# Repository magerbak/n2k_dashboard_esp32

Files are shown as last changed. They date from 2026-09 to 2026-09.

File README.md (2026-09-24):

# N2K Dashboard
Monitors the NMEA2000 bus and displays a simple dashboard of relevant sailing info.

* v.1.3.0 and earlier targeted the [Adafruit ESP32-S3 Reverse 1.14" TFT Feather](https://www.adafruit.com/products/5691). This is no longer supported.
* v.2.0.0 and later targets the [Hosyond ESP32-S3 2.8" IPS LCD display](https://a.co/d/04SSH8Cm) with a touch screen.
  * SPI-based 320x240 LCD with the ILI9341 driver.
  * TFT_eSPI GFX library. This project should work pretty seamlessly with any device supported by this library.
  * FT6336 touch device, but the touch logic is very basic and could be adapted to any touch driver.

Relies on the very useful https://github.com/ttlappalainen/NMEA2000 library and a custom version of the [NMEA2000_esp32](https://github.com/offspring/NMEA2000_esp32) library for the ESP32-S3 using the internal CAN controller (external transceiver required).

Approximate power consumption including an external transceiver and 12v to 5v buck converter is about 55mA.

# Overview
Provides top-level pages for wind, logbook and AIS info (at three different ranges). 

All headings and courses are relative to true North and speeds are in knots. Distances are in nautical miles. By default, depth is in feet, pressure in inHg and temperature in Farenheit but the code can be compiled with USE_METRIC defined to switch to meters, millibars and Celcius.

# Wind Info
Displays basic wind and other instrument data.



* The radial dial shows the apparent wind angle (AWA)
* Boat speed (SOG) and course (COG) are in the center in yellow.
* Apparent wind speed (AWS) and angle (AWA) are shown in red at the top with a 1 hour history graph of AWS.
* True wind speed (TWS) and angle (TWA) are shown in blue at the bottom with a 1 hour history graph of TWS.
* Depth is shown to the left in green.

Navigation:
* Tap AWS, TWS, SOG or Depth to view a detailed 60 minute history.
* Tap the Next page icon to the right to cycle to the logbook page.

## History Detail



The history detail page shows a 60 minute history of TWS, AWS, SOG or Depth with a bar showing the range of values occurring during each minute. The maximum, minimum and average values over the last 60 minutes are also shown. The vertical axis is divided every 10 units.

Navigation:
* Tap the graph title to cycle to another history graph.
* Tap anywhere in the body of the graph to return to the wind info page.

# Logbook Info
This page is intended to provide information for making logbook entries or radio calls.



Includes:
* Current time (UTC or Local)
* Ambient atmospheric pressure, air/sea temperature when provided.
* GPS position
* Log (trip) distance and time.
* True heading and course.
* Speed over ground and average trip speed.
* Apparent wind speed and angle
* True wind speed and direction (relative to true North).

The trip log is calculated by sampling GPS position every minute. The log distance and time are saved persistently.

Navigation:
* Tap the time to view historical on-the-hour snapshots.
* Tap the Trip Log to reset (tap again to confirm).
* Tap the Next page icon to the right to cycle to the AIS page.
  
## Logbook History
This page displays a snapshot of most of Logbook info on the hour for the last 4 hours. An initial snapshot is also taken when the system is first powered up once GPS position and time are acquired.



Navigation:
* Tap the time to cycle to a previous snapshot.
* Tap anywhere else to return to the main Logbook info page.

# AIS Info
Displays a North-up graphical representation of AIS targets within the selected range.



* Speed vectors in yellow show projected position in 5 minutes.
* Targets shown in red are considered potential collision issues (closest point of approach is < 1nm within the next hour).
* Selected vessel's range, true bearing and distance are displayed in green at bottom left.
* Selected vessel's MMSI/name is displayed in green at bottom right.
* If the selected vessel is converging, their closest point of approach (CPA) distance, bearing and time (mins) is shown at top right.
  * CPA is red if your vessel is projected to pass in front of the vessel.
  * CPA is orange if your vessel is projected to pass behind the vessel.
* Targets are removed 3 mins after their last report.

Navigation:
* Tap inside the range circles to cycle between targets.
* Tap MMSI/Name in the bottom right to display additional vessel information.
* Tap the range to cycle between 12nm, 6nm, 3nm, 1nm ranges.
* Tap the Next page icon to the right to cycle to the Wind info page.

## AIS Vessel Info
The additional vessel info subpage includes additional static data for the selected vessel such and length, beam and draft, vessel type, status and destination when provided.

PXL_20260921_183305165 MP

Navigation:
* Tap the vessel name to cycle between target.
* Tap anywhere else to return to the main AIS page.

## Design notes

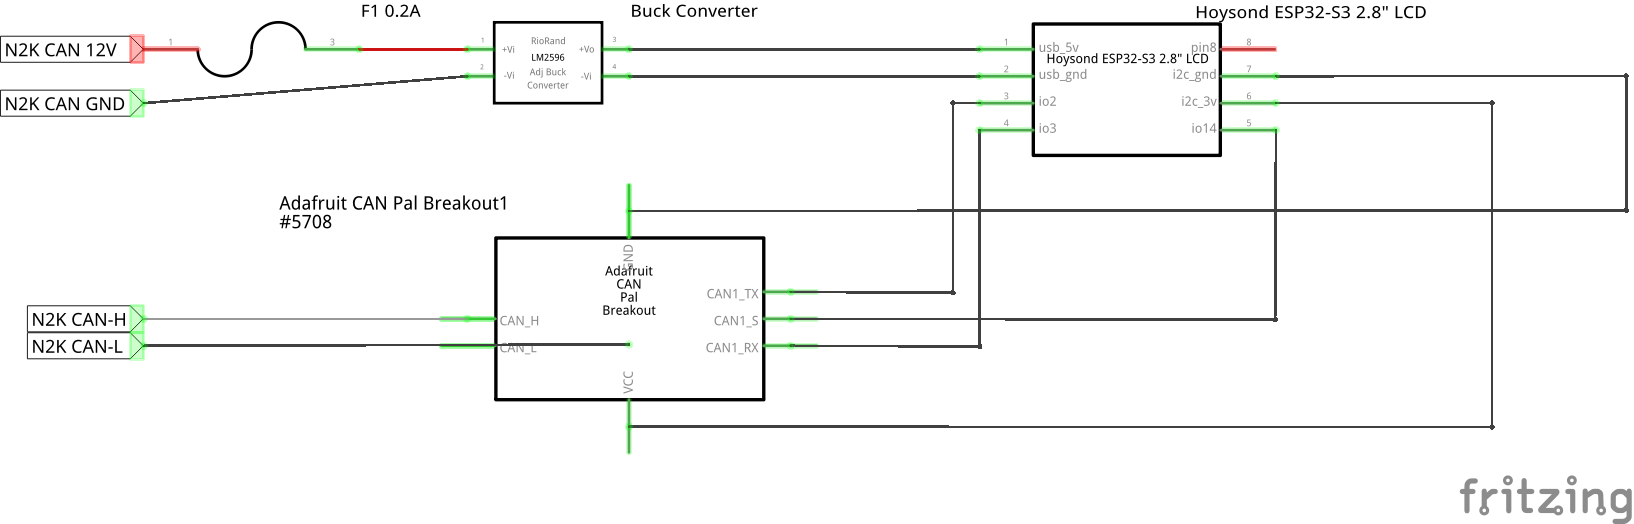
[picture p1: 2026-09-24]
schematics/n2k_dashboard_schem.png

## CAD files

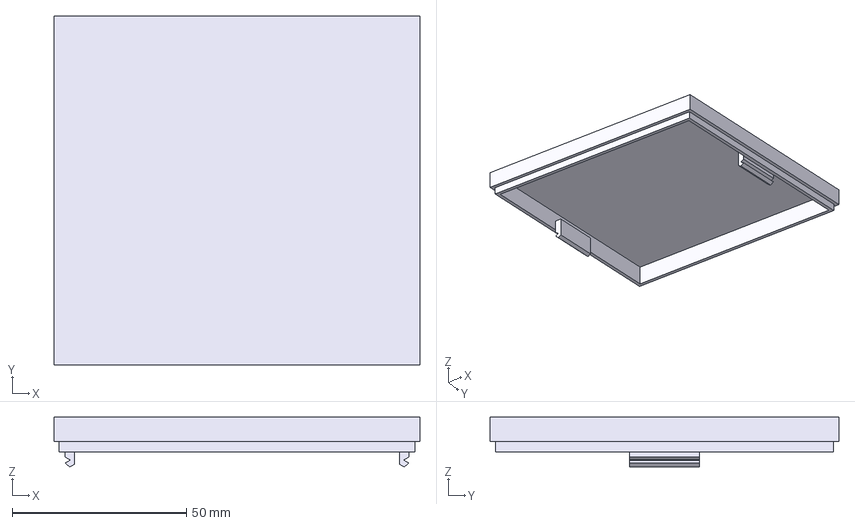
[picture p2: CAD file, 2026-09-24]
assets/NavDeskComboPanelLarge-Lid.step
105.0 x 100.0 x 14.3 mm

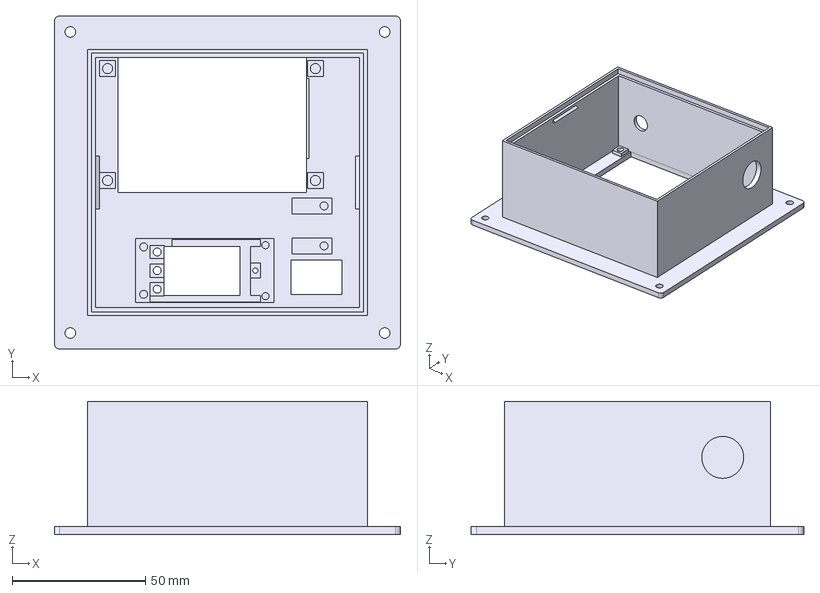
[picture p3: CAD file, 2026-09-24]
assets/NavDeskComboPanelLarge-Panel.step
130.0 x 125.0 x 50.0 mm

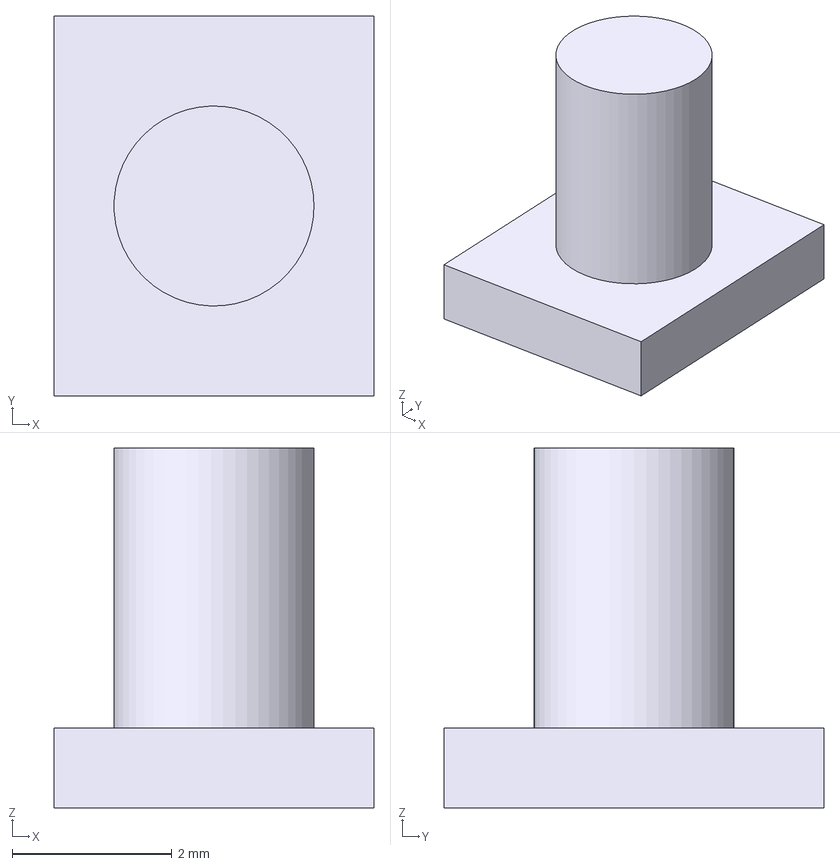
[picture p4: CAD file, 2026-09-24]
assets/NavDeskComboPanelLarge-ButtonActuator.step
4.00 x 4.75 x 4.50 mm

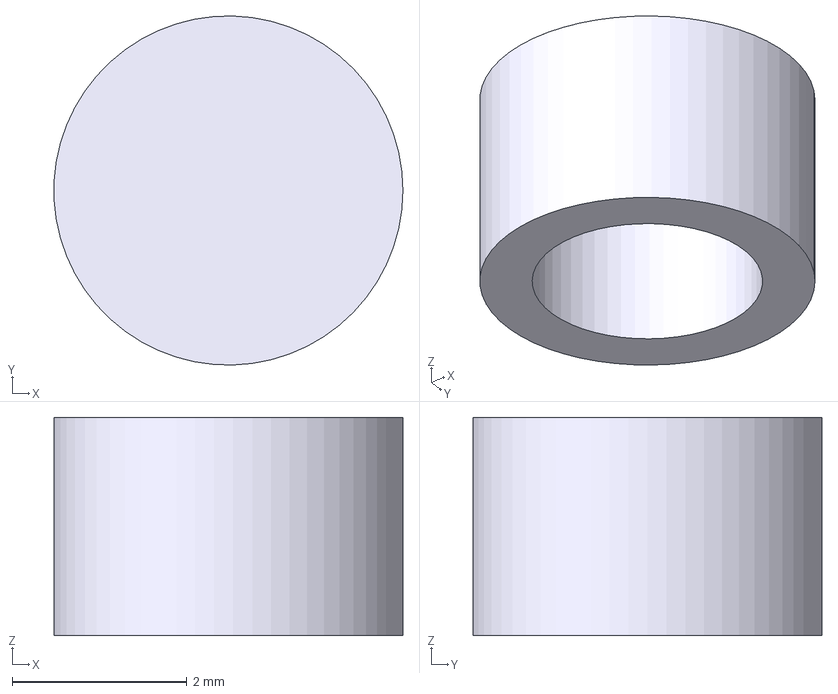
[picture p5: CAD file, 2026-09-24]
assets/NavDeskComboPanelLarge-ButtonActuatorPad.step
4.00 x 4.00 x 2.50 mm

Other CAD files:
assets/NavDeskComboPanelLarge-ButtonActuator.stl
assets/NavDeskComboPanelLarge-ButtonActuatorPad.stl
assets/NavDeskComboPanelLarge-Lid.stl
assets/NavDeskComboPanelLarge-Panel.stl

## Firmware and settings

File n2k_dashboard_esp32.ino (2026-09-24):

/**************************************************************************
  Monitors NMEA2000 bus and displays a simple dashboard of useful info.

  Works with the Hosyond ESP32-S3 2.8" IPS LCD display (https://a.co/d/04SSH8Cm)

  Compiles for Arduino using ESP32-S3 Dev Module board config.

  Uses TFT_eSPI and TFT_eWidget GFX libraries with ILI9341 driver and
  FT6336 touch screen driver.

  Uses the NEMA2000 library for parsing N2K communications using the ESP32
  internal CAN controller (external transceiver required).

 **************************************************************************/
#include "n2k_config.h"      // Build options

#include <limits>
#include <memory>
#include <list>
#include <Preferences.h>     // For persistent storage of log data

#include <TFT_eSPI.h>        // The library itself is modified to select a
                             // User_Setup.h for the appropriate display driver.
#include <TFT_eWidget.h>     // For graphing support
#include <SPI.h>

#define TOUCH_FT6336_SCL 15
#define TOUCH_FT6336_SDA 16
#define TOUCH_FT6336_INT 17
#define TOUCH_FT6336_RST 18
#include <FT6336.h>         // Touch screen uses I2C

#include "N2kMsg.h"
#include "NMEA2000.h"
#define ESP32_CAN_SILENT_PIN GPIO_NUM_14
#define ESP32_CAN_TX_PIN GPIO_NUM_2
#define ESP32_CAN_RX_PIN GPIO_NUM_3
#include <NMEA2000_esp32.h> // Custom NMEA2000_esp32 support for S3 (https://github.com/offspring/NMEA2000_esp32)
#include <N2kMessages.h>

#include "simple_timer.h"
#include "data_history.h"
#include "n2kvector.h"
#include "n2kpos.h"
#include "n2kunits.h"
#include "n2kaistarget.h"
#include "touch_rect.h"

#define VERSION_NUM      "v2.0.0"
#define UPDATE_INTERVAL  1
#define AIS_TIMEOUT      (3 * 60 + 10)

// Default magnetic variation, in case this is not provided from the network.
// Modify this value based on the region of operation.
#define DEFAULT_MAGNETIC_VARIATION (-14.0 * (M_PI / 180.0))  // Variation for Boston, MA in 2025.

// Interval that min/max data is sampled.
#define HISTORY_SAMPLE_INTERVAL_MS          1000
// Interval over which sampled min/max data is aggregated per data point in history.
#ifdef TESTING
  #define HISTORY_AGGREGATION_INTERVAL_MS   (10 * 1000)
  #define LOG_SAVE_INTERVAL_MS              (2 * 60 * 1000)
#else
  #define HISTORY_AGGREGATION_INTERVAL_MS   (60 * 1000)
  #define LOG_SAVE_INTERVAL_MS              (10 * 60 * 1000)
#endif
// Default number of data points in history - can be customized in setup().
// Total duration of history = num data points * HISTORY_AGGREGATION_INTERVAL_MS
#define HISTORY_DEF_NUM_DATA_POINTS         60

#define DISPLAY_WIDTH   320
#define DISPLAY_HEIGHT  240

#define ARROW_HEIGHT    25
#define ARROW_WIDTH     12

#define NUM_LOG_ENTRIES 4

// Display page
enum Page {
    PAGE_WIND,
    PAGE_POSITION,
    PAGE_AIS,

    NUM_PAGES
};

enum Subpage {
    SUBPAGE_NONE,

    // Wind supbages
    SUBPAGE_HIST_AWS,
    SUBPAGE_HIST_TWS,
    SUBPAGE_HIST_SOG,
    SUBPAGE_HIST_DEPTH,
    SUBPAGE_HIST_SEPARATOR,

    // Position subpages
    SUBPAGE_POS_LOG,

    // AIS subpages
    SUBPAGE_AIS_INFO,
};

enum Event {
    EVT_NONE,
    EVT_D0_PRESS,
    EVT_D0_RELEASE,
    EVT_D1_PRESS,
    EVT_D1_RELEASE,
    EVT_D2_PRESS,
    EVT_D2_RELEASE,
};

enum TextLayout {
    TXT_JUSTIFIED,
    TXT_CENTERED,
};

struct HistStatsContext {
    bool bFirst = true;

    size_t len = 0;     // Num samples of history

    // Stats for current history samples.
    double min = 0.0;
    double max = 1.0;
    double avg = 0.0;
};

// Trip log
struct LogData {
    uint32_t duration;
    float distance;
};

struct LogEntry {
    bool bInUse;

    uint16_t timestamp;     // minutes since midnight
    int16_t tzOffset;       // timezone offset or 0 if unknown.

    N2kPos position;
    double heading;
    N2kVector velocity;
    N2kVector appWind;
    LogData logData;
    float atmPressure;
    float atmTemp;
    float seaTemp;
};

// Abbreviations for TFT_eSPI fonts.
#define GFXFF 1

// These are modified versions of the standard GFX FreeFonts with the same
// filename, that replace the '~' character with the '°' symbol for convenience.
// The Fonts directory includes the 48 fonts from the TFT_eSPI library but we
// only include 3.
#include "Fonts/FreeSansBold9pt7b.h"
#include "Fonts/FreeSansBold12pt7b.h"
#include "Fonts/FreeSansBold18pt7b.h"

// The font names have a Mod suffix to distinguish them from the stock fonts.
#define FONT_SMALL  &FreeSansBoldMod9pt7b
#define FONT_MEDIUM &FreeSansBoldMod12pt7b
#define FONT_LARGE  &FreeSansBoldMod18pt7b

// fontHeight() returns a line-spacing that accounts for ascending and descending
// lowercase characters. Since we are primarily using uppercase, this additional
// spacing looks overly generous, so we use a more compact spacing instead.
#define FONT_SMALL_ADJ_HEIGHT   (21 - 5)
#define FONT_MEDIUM_ADJ_HEIGHT  (28 - 6)
#define FONT_LARGE_ADJ_HEIGHT   (42 - 9)

// Pin usage as follow:
//             CS  DC/RS  RESET  SDI/MOSI  SCK  SDO/MISO  LED    VCC     GND
// ESP32-S3:   10    2      15      11      12      13     21     5V     GND
TFT_eSPI g_tft;

// Default orientation is portrait (240x320)
FT6336 g_ts = FT6336(TOUCH_FT6336_SDA, TOUCH_FT6336_SCL, TOUCH_FT6336_INT,
                     TOUCH_FT6336_RST, DISPLAY_HEIGHT, DISPLAY_WIDTH);

tNMEA2000 &g_NMEA2000 = *(new tNMEA2000_esp32());

// UI state
Page g_page = PAGE_WIND;
Subpage g_subpage = SUBPAGE_NONE;
double g_aisRange = 12.0;

// Common to all pages
TouchRect g_nextPageRect;

// Wind Page touch rects
TouchRect g_awsRect;
TouchRect g_depthRect;
TouchRect g_twsRect;
TouchRect g_sogRect;

// Position Page touch rects
TouchRect g_timeRect;
TouchRect g_logResetRect;

// AIS Page touch rects
TouchRect g_rangeRect;
TouchRect g_selectRect;
TouchRect g_detailRect;

// Subpage rects
TouchRect g_subTitleRect;
TouchRect g_subBodyRect;

float g_envAtmPressure = std::numeric_limits<float>::quiet_NaN();
float g_envAtmTemp = std::numeric_limits<float>::quiet_NaN();
float g_envAtmHumidity = std::numeric_limits<float>::quiet_NaN();
float g_envSeaTemp = std::numeric_limits<float>::quiet_NaN();;

#ifdef USE_METRIC_PRESSURE
static const int g_precPressure = 0;
static const char g_unitsPressure[] = "mb";
#else
static const int g_precPressure = 2;
static const char g_unitsPressure[] = { '"', '\0' };
#endif
#ifdef USE_METRIC
static const char g_unitsTemp[] = "C";
static const char g_unitsDepth[] = "m";
#else
static const char g_unitsTemp[] = "F";
static const char g_unitsDepth[] = "ft";
#endif

// Log data
Preferences g_prefs;
LogData g_tripLog;          // Duration and distance of current trip
bool g_tripResetConfirmation = false;
N2kPos g_lastPos;           // Lat/Long of last log sample

LogEntry g_logEntries[NUM_LOG_ENTRIES];
unsigned int g_logEntryIndex;   // Index of next entry to store.
unsigned int g_selLogEntry; // Reverse index of displayed entry

uint16_t g_date;            // Days since 1/1/1970
double g_secsSinceMidnight; // Seconds since midnight
int16_t g_tzOffset;         // Timezone offset in minutes, if known

bool g_bPosValid = false;
N2kPos g_localPos;          // Latitude and Longitude
N2kVector g_localVelocity;  // Boat COG (in degrees) and SOG (kts) as a vector
double g_hdg = 0.0;         // degrees
double g_variation = DEFAULT_MAGNETIC_VARIATION; // radians

double g_depth = 0.0;       // ft
N2kVector g_appWind;        // Degrees, knots
N2kVector g_trueWind;       // Degrees, knots

// AIS state
std::list<std::unique_ptr<N2kAISTarget>> g_targets;
uint32_t g_selTarget = 0;   // MMSI of selected AIS target

// 1s timer for refreshing data model (ageing out AIS targets, sampling data history).
SimpleTimer g_updateTimer;

// 60s timer for recording aggregate min/max history and log data.
SimpleTimer g_historyTimer;

// 10min timer to save trip log data
SimpleTimer g_tripLogTimer;

// Timer for recording on-the-hour log entries
SimpleTimer g_hourTimer;

MinMaxDataHistory<double> g_awsHistory;
MinMaxDataHistory<double> g_twsHistory;
MinMaxDataHistory<double> g_sogHistory;
MinMaxDataHistory<double> g_depthHistory;

// Time since last display update in seconds.
time_t g_lastUpdate = 0;

void setup(void) {
  Serial.begin(115200);
  delay(2000);
  Serial.println(F("Starting N2K dashboard"));

  g_prefs.begin("n2k_dashboard");

  g_tripLog.duration = g_prefs.getUInt("tripLogTime", 0);
  g_tripLog.distance = g_prefs.getFloat("tripLogDist", 0.0);

  // Optionally, set N2k transceiver to silent mode. This only works if there is
  // more than one device on the N2K network. If testing with a single transmitter,
  // then our transmit must remain enabled so it can ACK messages.
  pinMode(ESP32_CAN_SILENT_PIN, OUTPUT);
  digitalWrite(ESP32_CAN_SILENT_PIN, LOW /* HIGH */); // not silent

  g_updateTimer.begin(nullptr, HISTORY_SAMPLE_INTERVAL_MS, updateCallback);
  g_historyTimer.begin(nullptr, HISTORY_AGGREGATION_INTERVAL_MS, historyCallback);
  g_tripLogTimer.begin(nullptr, LOG_SAVE_INTERVAL_MS, logCallback);

  // Record history of AWS, TWS and SOG for last 60mins.
  g_awsHistory.begin(60);
  g_twsHistory.begin(60);
  g_sogHistory.begin(60);
  g_depthHistory.begin(60);

  // initialize TFT
  g_tft.init();
  g_tft.setRotation(1);
  g_ts.begin();
  g_ts.setRotation(1);

  setupTouchRects();

  displaySplashScreen();

  delay(1000);
  displayUpdate(true);

  //NMEA2000.SetN2kCANMsgBufSize(8);
  //NMEA2000.SetN2kCANReceiveFrameBufSize(100);
  g_NMEA2000.EnableForward(false);  // Disable all msg forwarding to USB (=Serial)
  g_NMEA2000.SetMsgHandler(handleNMEA2000Msg);
  g_NMEA2000.Open();
  Serial.println(F("N2k Initialized"));
}

void loop() {
    uint32_t t = millis();

    handleTouchEvents();

    // Drive our timers
    g_updateTimer.tick(t);
    g_historyTimer.tick(t);
    g_tripLogTimer.tick(t);
    g_hourTimer.tick(t);

    // Handle incoming N2K messages.
    g_NMEA2000.ParseMessages();
}

void setupTouchRects() {
    g_nextPageRect.init(DISPLAY_WIDTH - ARROW_WIDTH - 30, DISPLAY_HEIGHT / 2 - ARROW_HEIGHT / 2 - 10,
                        ARROW_WIDTH + 15 + 15, ARROW_HEIGHT + 10 * 2);
    g_nextPageRect.setReleaseCallback(handleNextPageCallback, nullptr);

    g_awsRect.init(0, 0, 70, 60);
    g_awsRect.setReleaseCallback(handleAwsCallback,  nullptr);

    g_depthRect.init(0, DISPLAY_HEIGHT / 2 - 30, 70, 60);
    g_depthRect.setReleaseCallback(handleDepthCallback,  nullptr);

    g_twsRect.init(0, DISPLAY_HEIGHT - 60, 70, 60);
    g_twsRect.setReleaseCallback(handleTwsCallback,  nullptr);

    g_sogRect.init(DISPLAY_WIDTH / 2 - 40, DISPLAY_HEIGHT / 2 - 40, 80, 80);
    g_sogRect.setReleaseCallback(handleSogCallback,  nullptr);


    g_timeRect.init(0, 0, DISPLAY_WIDTH / 2, 40);
    g_timeRect.setReleaseCallback(handleTimeCallback,  nullptr);

    g_logResetRect.init(0, FONT_MEDIUM_ADJ_HEIGHT * 4 - 5, DISPLAY_WIDTH / 2, FONT_MEDIUM_ADJ_HEIGHT + 15);
    g_logResetRect.setReleaseCallback(handleLogResetCallback,  nullptr);


    g_rangeRect.init(0, 0, DISPLAY_WIDTH / 3, 50);
    g_rangeRect.setReleaseCallback(handleRangeCallback,  nullptr);

    g_selectRect.init(DISPLAY_WIDTH / 2 - 90, DISPLAY_HEIGHT / 2 - 60, 180, 120);
    g_selectRect.setReleaseCallback(handleSelectCallback,  nullptr);

    g_detailRect.init(DISPLAY_WIDTH - DISPLAY_WIDTH / 2, DISPLAY_HEIGHT - 40, DISPLAY_WIDTH / 2, 40);
    g_detailRect.setReleaseCallback(handleDetailCallback,  nullptr);

    g_subTitleRect.init(0, 0, DISPLAY_WIDTH, 50);
    g_subTitleRect.setReleaseCallback(handleSubTitleCallback,  nullptr);

    g_subBodyRect.init(0, 40, DISPLAY_WIDTH, DISPLAY_HEIGHT - 50);
    g_subBodyRect.setReleaseCallback(handleSubBodyCallback,  nullptr);
}


void handleTouchEvents() {
    uint16_t x = 0;
    uint16_t y = 0;
    bool bPressed = false;

    g_ts.read();
    if (g_ts.isTouched) {
        x = g_ts.points[0].x;
        y = g_ts.points[0].y;
        bPressed = true;
    }

    if (g_subpage == SUBPAGE_NONE) {
        // All top level pages have a next page button
        g_nextPageRect.update(bPressed, x, y);

        switch (g_page) {
            case PAGE_WIND:
                g_awsRect.update(bPressed, x, y);
                g_depthRect.update(bPressed, x, y);
                g_twsRect.update(bPressed, x, y);
                g_sogRect.update(bPressed, x, y);
                break;

            case PAGE_POSITION:
                g_timeRect.update(bPressed, x, y);
                g_logResetRect.update(bPressed, x, y);
                break;

            case PAGE_AIS:
                g_rangeRect.update(bPressed, x, y);
                g_selectRect.update(bPressed, x, y);
                g_detailRect.update(bPressed, x, y);
                break;
        }
    }
    else {
        // For now subpages only care about touch events to the first row of
        // text or the rest of the page.
        g_subTitleRect.update(bPressed, x, y);
        g_subBodyRect.update(bPressed, x, y);
    }
}

void handleNextPageCallback(void* user) {
    int pg = (int)g_page + 1;
    if (pg >= NUM_PAGES) {
        pg = PAGE_WIND;
    }
    g_page = (Page)pg;
    g_tripResetConfirmation = false;

    displayUpdate(true);
}

void handleAwsCallback(void* user) {
    g_subpage = SUBPAGE_HIST_AWS;

    displayUpdate(true);
}

void handleDepthCallback(void* user) {
    g_subpage = SUBPAGE_HIST_DEPTH;

    displayUpdate(true);
}

void handleTwsCallback(void* user) {
    g_subpage = SUBPAGE_HIST_TWS;

    displayUpdate(true);
}

void handleSogCallback(void* user) {
    g_subpage = SUBPAGE_HIST_SOG;

    displayUpdate(true);
}

void handleTimeCallback(void* user) {
    g_selLogEntry = 0;
    g_subpage = SUBPAGE_POS_LOG;
    g_tripResetConfirmation = false;

    displayUpdate(true);
}

void handleLogResetCallback(void* user) {
   if (g_tripResetConfirmation) {
        g_tripLog.duration = 0;
        g_tripLog.distance = 0.0;
        g_prefs.putUInt("tripLogTime", g_tripLog.duration);
        g_prefs.putFloat("tripLogDist", g_tripLog.distance);
        g_tripResetConfirmation = false;
    }
    else {
        g_tripResetConfirmation = true;
    }
}

void handleRangeCallback(void* user) {
    // Cycle through ranges
    if (g_aisRange == 1.0) {
        g_aisRange = 12.0;
    }
    else if (g_aisRange == 3.0) {
        g_aisRange = 1.0;
    }
    else {
        g_aisRange = g_aisRange / 2.0;
    }

    displayUpdate(true);
}

void handleSelectCallback(void* user) {
    // Cycle forward through targets
    setTarget(cycleAisTarget(g_targets, g_selTarget));

    displayUpdate(true);
}

void handleDetailCallback(void* user) {
    g_subpage = SUBPAGE_AIS_INFO;

    displayUpdate(true);
}

void handleSubTitleCallback(void* user) {
    switch (g_subpage) {
        case SUBPAGE_HIST_AWS:
        case SUBPAGE_HIST_TWS:
        case SUBPAGE_HIST_SOG:
        case SUBPAGE_HIST_DEPTH:
            {
                int sub = (int)g_subpage + 1;
                if (sub >= SUBPAGE_HIST_SEPARATOR) {
                    sub = SUBPAGE_HIST_AWS;
                }
                g_subpage = (Subpage)sub;
            }
            break;

        case SUBPAGE_POS_LOG:
            {
                unsigned int ix = (g_selLogEntry + 1) % NUM_LOG_ENTRIES;
                if (g_logEntries[ix].bInUse == false) {
                    ix = 0;
                }
                g_selLogEntry = ix;
            }
            break;

        case SUBPAGE_AIS_INFO:
            // Cycle forward through targets
            setTarget(cycleAisTarget(g_targets, g_selTarget));
            break;
    }

    displayUpdate(true);
}

void handleSubBodyCallback(void* user) {
    g_subpage = SUBPAGE_NONE;

    displayUpdate(true);
}


void drawArrowRight(int16_t x, int16_t y) {
    g_tft.drawWideLine(x - ARROW_WIDTH, y - ARROW_HEIGHT / 2, x, y, 5, TFT_DARKGREY);
    g_tft.drawWideLine(x, y, x - ARROW_WIDTH, y + ARROW_HEIGHT / 2, 5, TFT_DARKGREY);
}


const N2kAISTarget* cycleAisTarget(const std::list<std::unique_ptr<N2kAISTarget>>& targets,
                                   uint32_t selMmsi) {
    const N2kAISTarget* last = nullptr;

    for (auto& t : targets) {
        if (!isVisibleTarget(t.get())) {
            continue;
        }

        if (selMmsi == 0 || (last && last->getMmsi() == selMmsi)) {
            return t.get();
        }
        last = t.get();
    }

    return nullptr;
}

// Time-based refresh of our data model. This may update the display based on
// what changes.
bool updateCallback(void* user) {
    bool bChanged = false;
    time_t now = time(nullptr);

    (void)user;

    // Age out stale AIS targets
    for (auto t = g_targets.begin(); t != g_targets.end();) {
        if ((*t)->getTimestamp() && now - (*t)->getTimestamp() > AIS_TIMEOUT) {
            if ((*t)->getMmsi() == g_selTarget) {
                setTarget(nullptr);
            }
            t = g_targets.erase(t);
            bChanged = true;
        }
        else {
            ++t;
        }
    }

    // Update the min/max value for current history data point.
    g_awsHistory.updateData(g_appWind.getMagnitude());
    g_twsHistory.updateData(g_trueWind.getMagnitude());
    g_sogHistory.updateData(g_localVelocity.getMagnitude());
    g_depthHistory.updateData(g_depth);

    if (bChanged) {
        displayUpdate(true);
    }

    // Continue running
    return true;
}

bool historyCallback(void* user) {
    // Record the next data point for each history.
    g_awsHistory.updateHistory();
    g_twsHistory.updateHistory();
    g_sogHistory.updateHistory();
    g_depthHistory.updateHistory();

    // Sample position and accumulate running distance and time
    if (g_bPosValid) {
        N2kVector dist = g_localPos.getRelDistance(g_lastPos);
        g_tripLog.duration += HISTORY_AGGREGATION_INTERVAL_MS / 1000;
        g_tripLog.distance += dist.getMagnitude();
        g_lastPos = g_localPos;
    }

    // Force a display refresh every so often even if we're not receiving data
    displayUpdate(true);

    // Continue running
    return true;
}

bool logCallback(void* user) {
    // Persist the accumulated log data
    g_prefs.putUInt("tripLogTime", g_tripLog.duration);
    g_prefs.putFloat("tripLogDist", g_tripLog.distance);

    // Continue running
    return true;
}

bool logEntryCallback(void* user) {
    // Snapshot logbook entry data on the hour
    addLogEntry();

    // Make sure next interval is 1hr because the first time it is not.
    SimpleTimer* t = (SimpleTimer*)user;
    if (t) {
        t->setInterval(3600 * 1000);
    }
    return true;
}

void displaySplashScreen() {
    g_tft.fillScreen(TFT_BLACK);

    // Version in bottom right
    g_tft.setFreeFont(FONT_SMALL);
    g_tft.setTextSize(1);
    g_tft.setTextColor(TFT_YELLOW);

    g_tft.setTextDatum(BR_DATUM);
    g_tft.drawString(VERSION_NUM, DISPLAY_WIDTH, DISPLAY_HEIGHT, GFXFF);

    // Welcome message centered
    g_tft.setFreeFont(FONT_MEDIUM);
    g_tft.setTextColor(TFT_GREEN, TFT_BLACK);

    g_tft.setTextDatum(MC_DATUM);
    g_tft.drawString("Hello Michael", DISPLAY_WIDTH / 2, DISPLAY_HEIGHT / 2, GFXFF);

    g_tft.setTextDatum(TL_DATUM);
}

// Helper function to print a floating point value using a calculated starting
// position based on its displayed length and a layout option.
void drawJustifiedVal(double val, int precision, const char* suffix, int x, int y, int datum) {
    char str[64];

    if (!suffix) {
        suffix = "";
    }

    int rc = snprintf(str, sizeof(str), "%.*f%s", precision, val, suffix);

    g_tft.setTextDatum(datum);
    g_tft.drawString(str, x, y);
}


//
// Wind info top-level page.
//
void displayPageWind() {
    const int radius = 90;
    GraphWidget graph1(&g_tft);
    GraphWidget graph2(&g_tft);

    int x0 = DISPLAY_WIDTH / 2;
    int y0 = DISPLAY_HEIGHT / 2;

    g_tft.setTextWrap(false);

    // Wind info in large font
    g_tft.setFreeFont(FONT_LARGE);

    g_tft.fillScreen(TFT_BLACK);
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

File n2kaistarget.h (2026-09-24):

#pragma once

#include <stdint.h>
#include <stddef.h>
#include <time.h>

#include "n2kpos.h"
#include "n2kvector.h"
#include "n2kcpa.h"

// Represents an AIS target.
//
// MMSI is used as the unique identifier for each object and is required at
// construction time.
//
// Depending on which messages have been subsequently received, only a subset
// of information may be populated.
//
// In particular, static vessel info (length, name, etc) is generally received
// separately from dynamic info (position, speed, etc). Class B reports contain
// a subset of class A information.
//
// getTimestamp will return 0 until dynamic data has been set.
//
// getName will return the MMSI in the absence of static vessel name info.
//
// calcCPA will be ignored until dynamic position info has been received.
class N2kAISTarget
{
public:
    N2kAISTarget(uint32_t mmsi);
    ~N2kAISTarget() = default;

    enum AISClass {
        CLASS_B,
        CLASS_A,
    };

    enum NavStatus {
        NAV_STATUS_UNDER_WAY_MOTORING = 0,
        NAV_STATUS_AT_ANCHOR = 1,
        NAV_STATUS_NOT_UNDER_COMMAND = 2,
        NAV_STATUS_RESTRICTED_MANOEUVERABILITY = 3,
        NAV_STATUS_CONSTRAINED_BY_DRAUGHT = 4,
        NAV_STATUS_MOORED = 5,
        NAV_STATUS_AGROUND = 6,
        NAV_STATUS_FISHING = 7,
        NAV_STATUS_UNDER_WAY_SAILING = 8,
        NAV_STATUS_HAZARDOUS_MATERIAL_HIGH_SPEED = 9,
        NAV_STATUS_HAZARDOUS_MATERIAL_WING_IN_GROUND = 10,
        NAV_STATUS_AIS_SART = 14,
    };

    const time_t getTimestamp() const { return m_timestamp; }
    uint32_t getMmsi() const { return m_mmsi; }
    const char* getName() const { return m_name; }
    AISClass getClass() const { return m_class; }

    const char* getDest() const { return m_dest; }

    NavStatus getNavStatus() const { return m_navStatus; }
    const char* getNavStatusStr() const;

    uint8_t getVesselType() const { return m_type; }
    const char* getVesselTypeStr() const;

    double getLength() const { return m_length; }
    double getBeam() const { return m_beam; }
    double getDraft() const { return m_draft; }

    void update(const N2kPos &pos, const N2kVector &vel, NavStatus status);
    void update(const N2kPos& pos, const N2kVector& vel);
    void update(const char* name);
    void update(uint8_t type, double length, double beam, double draft,
                const char* callsign, const char* name, const char* dest);

    void calcCpa(const N2kPos &ref, const N2kVector &refVelocity);
    const N2kVector& getRelDistance() const { return m_relDistance; }
    const N2kVector& getVelocity() const { return m_velocity; }
    const Cpa* getCpa() const { return &m_cpa; }

    bool toString(char* buffer, size_t len) const;
    bool toStringVesselInfo(char* buffer, size_t len) const;

private:
    static const char* s_navStatusTable[NAV_STATUS_AIS_SART + 1];
    static bool copyTrimmed(char* dest, const char* src, size_t size);

    // Time of last position update
    time_t m_timestamp = 0;

    uint32_t m_mmsi = 0;
    AISClass m_class = CLASS_B;

    N2kPos m_pos;
    N2kVector m_velocity;
    NavStatus m_navStatus = NAV_STATUS_UNDER_WAY_MOTORING;

    uint8_t m_type = 0;
    double m_length = 0;
    double m_beam = 0;
    double m_draft = 0;
    char m_callsign[7 + 1] = { };
    char m_name[20 + 1] = { };
    char m_dest[20 + 1] = { };

    N2kVector m_relDistance;
    Cpa m_cpa;
};

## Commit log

2025-12-05 Fix AIS y-axis bug
    [n2k_dashboard_esp32.ino]
2025-12-10 Fixed timestamp bug. Add selected target info
    [n2k_dashboard_esp32.ino, n2kaistarget.h]
2025-12-21 Add heading decode and fix TWD
    [n2k_dashboard_esp32.ino]
2025-12-26 Fix typos and normalize TWD
    [n2k_dashboard_esp32.ino]
2025-12-26 Fix signed bearing for AWA and TWA, fix NAN test for NMEA2000 parsed values
    [n2k_dashboard_esp32.ino]
2025-12-30 Change AIS ranges to 12, 6 and 3nm
2026-02-25 Switch wind info layout to put apparent wind at top, and speed then angle
2026-03-03 v1.0.1. Fix some bugs with wind speed
    [n2k_dashboard_esp32.ino]
2026-03-10 v1.0.5 Use magnetic variation from N2K bus
2026-03-10 v1.0.6 Fix AIS length units, and a button handling bug
    [n2k_dashboard_esp32.ino]
2026-06-21 v1.0.7 Fix for distance log
    [n2k_dashboard_esp32.ino]
2026-07-07 v1.1.0 added pressure and temp sensor support. Bugfixes
    [n2k_dashboard_esp32.ino]
2026-07-07 Add schematics and assets folders
    [NavDeskComboPanel-ButtonActuator.step, NavDeskComboPanel-ButtonActuator.stl, NavDeskComboPanel-ButtonActuatorPad.step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]
2026-08-04 Add support for PGNs 130312, 130314 for sea temp and atm pressure.
    Read atm pressure, atm temp and sea temp from N2K bus and incorporate into log info page.
    Take an initial log history snapshot at startup once we have position and time.
    Testing for Temp/Pressure PGNs. Take log snapshot at startup
2026-08-04 v1.3.0 Add 1nm AIS range
2026-09-24 Dropped support for Adafruit Reverse Feather and replaced with a generic ESP32-S3 2.8" touch LCD module. * Switched to using TFT_eSPI GFX graphics library * Added custom GFX fonts that use ~ for degr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
    Update README.md with screenshots
    Update CAD and schematic assets for 2.8in display
    [NavDeskComboPanel-ButtonActuator.step, NavDeskComboPanel-ButtonActuator.stl, NavDeskComboPanel-ButtonActuatorPad.step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]
